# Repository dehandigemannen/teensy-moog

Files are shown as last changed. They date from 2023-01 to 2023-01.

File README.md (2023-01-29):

# Teensymoog board[untested]
> Simple board to provide inputs for the teensy audio library

## Components
A list of components can be found [here](https://docs.google.com/spreadsheets/d/1O3fiJveS2LG4Vu1J4wDSkKv0wMXK735ehudC7_bgVOY/edit?usp=sharing)

> This board uses the teensy 3.6 board with build-in dac, the next version of the board should work with the teensy 4.1 because of the shortage of the 3.6 teensy.

## Preview
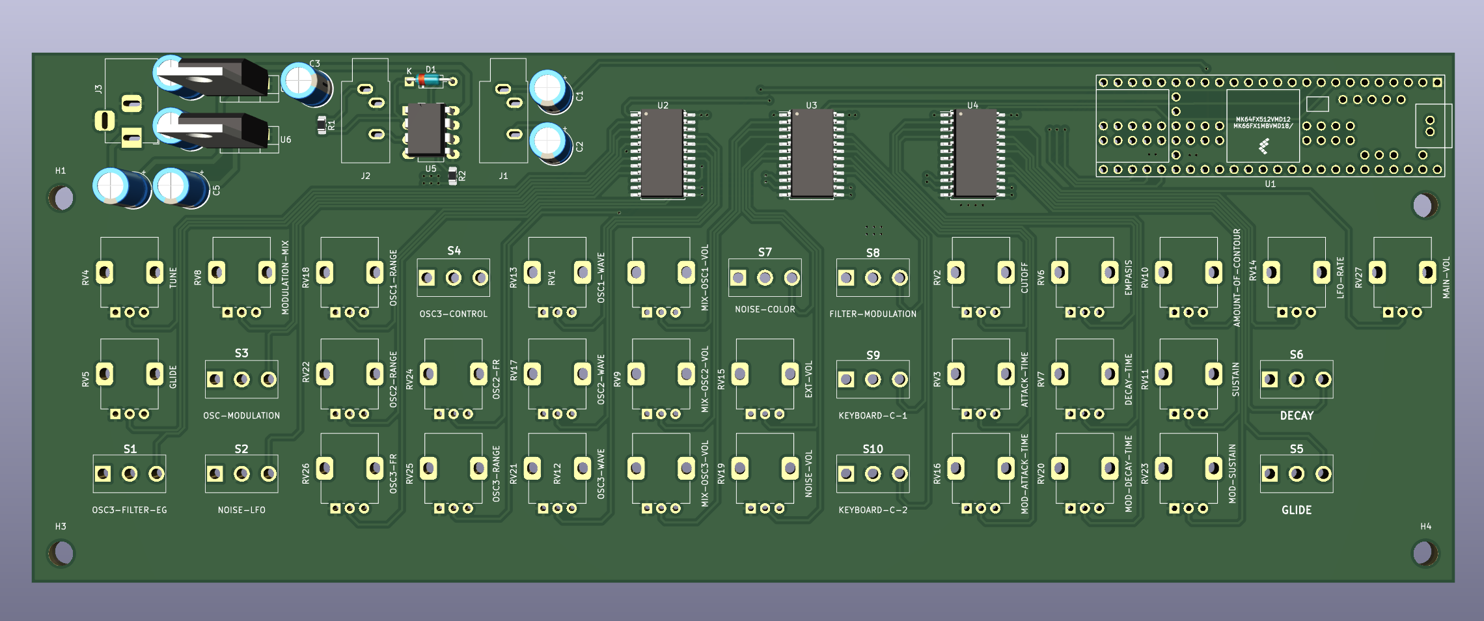
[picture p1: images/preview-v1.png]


## Rev2

- [] Connect switches to 3.3 V instead of ground.
- [] Create multiple boards to compensate for hight difference of pots and switches
- [] Use toggle switches that are on / of

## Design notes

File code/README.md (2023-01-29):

# Teensymoog - code

## Pins

```
TUNE = MUX_1_7
GLIDE = MUX_1_6
FILTER_EG = MUX_1_5 // SWITCH

MOD_MIX = MUX_1_4
MODULATION = MUX_1_2 // SWITCH
NOISE_LFO = MUX_1_1  // SWITCH

OSC_1_RANG = MUX_1_0
OSC_2_RANG = MUX_1_8
OSC_3_FR = MUX_1_14

OSC_3_CONTROL = MUX_1_3 // SWITCH
OSC_2_FR = MUX_1_13
OSC_3_RANGE = MUX_1_9

OSC_1_WAVE = MUX_1_12
OSC_2_WAVE = MUX_1_11
OSC_3_WAVE = MUX_1_10

OSC_1_VOL = MUX_2_7
OSC_2_VOL = MUX_2_6
OSC_3_VOL = MUX_2_5

NOISE_COLOR = MUX_2_4 // SWITCH
EXT_VOL = MUX_2_3
NOISE_VOL = MUX_2_2

FILTER_MOD = MUX_2_15   // SWITCH
KEYBOARD_C_1 = MUX_2_14 // SWITCH
KEYBOARD_C_2 = MUX_2_13 // SWITCH

CUTOFF = MUX_2_12
ATTACK_TIME = MUX_2_11
MOD_ATTACK_TIME = MUX_2_10

EMPHASIS = MUX_3_7
DECAY_TIME = MUX_3_6
MOD_DECAY_TIME = MUX_3_5

AMOUNT_OF_CONTOUR = MUX_3_15
SUSTAIN = MUX_3_14
MOD_SUSTAIN = MUX_3_13

LFO_RATE = MUX_3_10
DECAY = MUX_3_11 // SWITCH
GLIDE = MUX_3_12 // SWITCH

MAIN_VOL = MUX_3_9
```

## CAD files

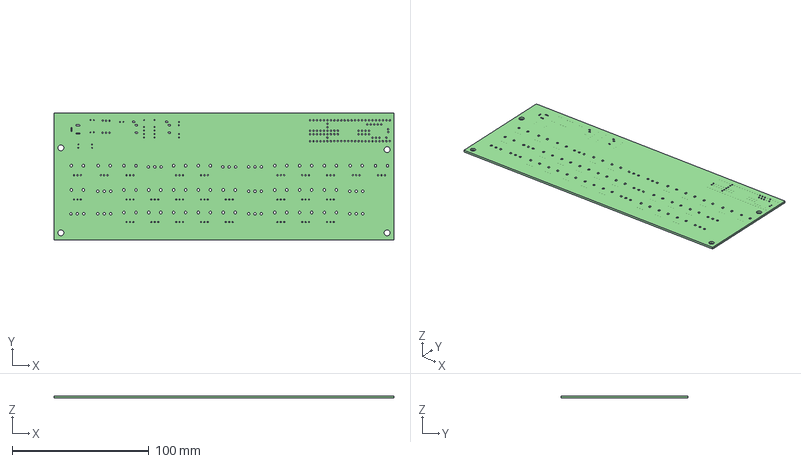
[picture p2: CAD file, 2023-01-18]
pcb/teensymoog.step
248.9 x 92.7 x 1.60 mm

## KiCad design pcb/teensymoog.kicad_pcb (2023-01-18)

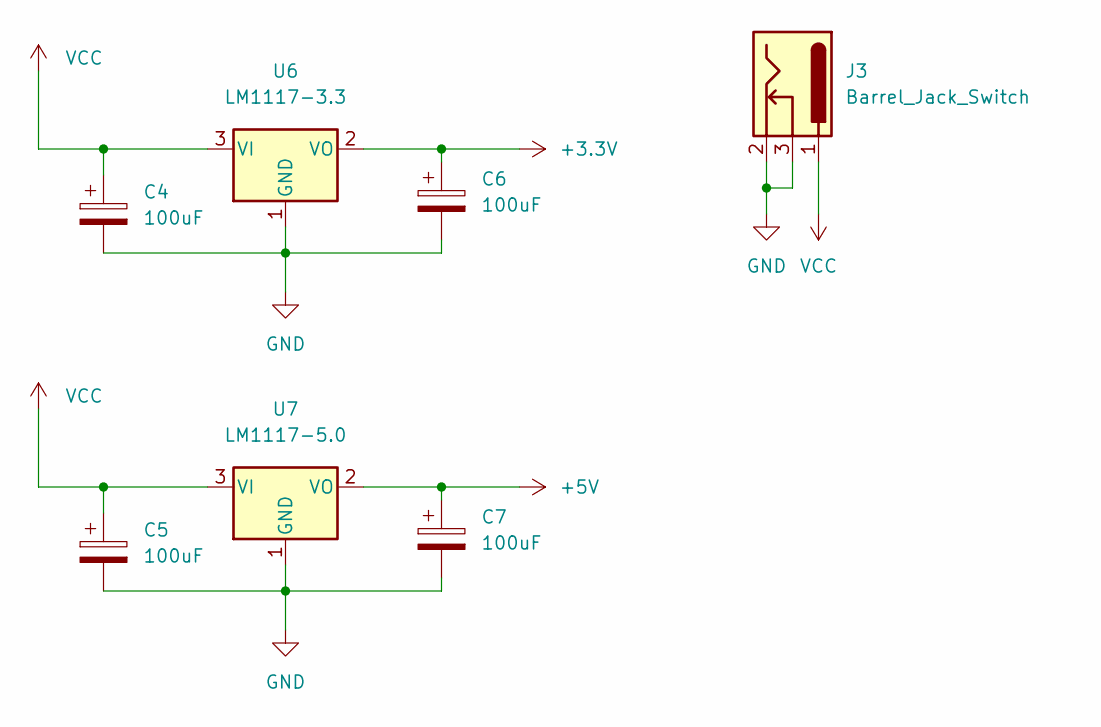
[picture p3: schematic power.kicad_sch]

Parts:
C4, C5, C6, C7: 100uF; CP_Radial_D6.3mm_P2.50mm
J3: Barrel_Jack_Switch; BarrelJack_Horizontal
U6: LM1117-3.3; TO-220-3_Vertical
U7: LM1117-5.0; TO-220-3_Vertical

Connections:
+3V3: C6.1, U6.2 (VO); also elsewhere on the board
+5V: C7.1, U7.2 (VO); also elsewhere on the board
GND: C4.2, C5.2, C6.2, C7.2, J3.2, J3.3, U6.1 (GND), U7.1 (GND); also elsewhere on the board
VCC: C4.1, C5.1, J3.1, U6.3 (VI), U7.3 (VI)

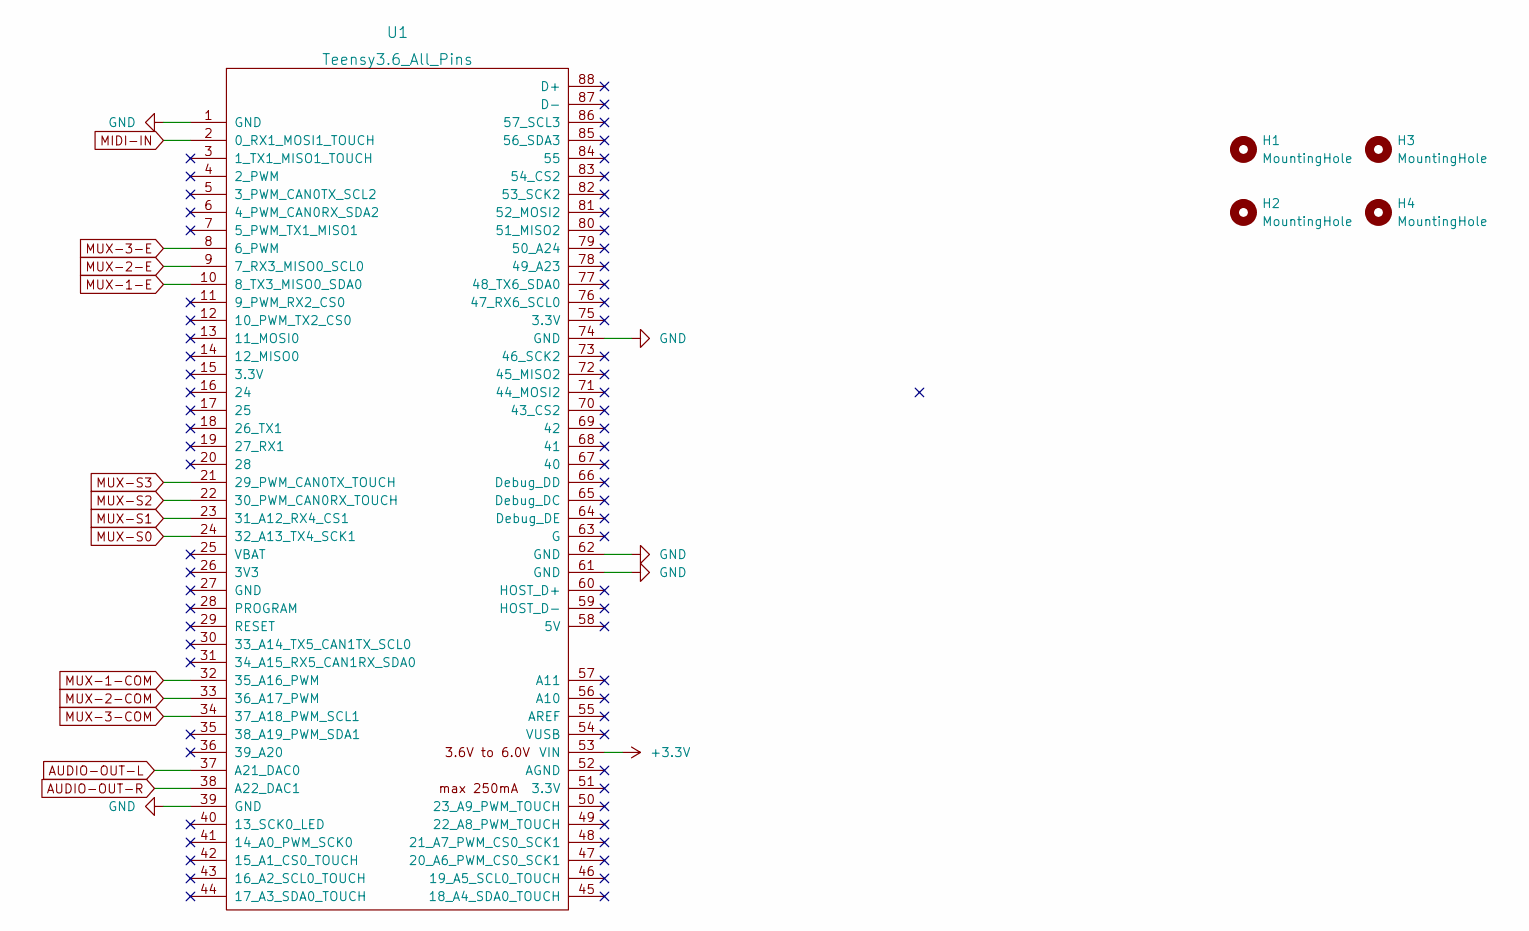
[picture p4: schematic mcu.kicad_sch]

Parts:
H1, H2, H3, H4: MountingHole; MountingHole_4.3mm_M4_DIN965
U1: Teensy3.6_All_Pins; Teensy35_36_All_Pins

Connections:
+3V3: U1.53 (VIN); also elsewhere on the board
AUDIO-OUT-L: U1.37 (A21_DAC0); also elsewhere on the board
AUDIO-OUT-R: U1.38 (A22_DAC1); also elsewhere on the board
GND: U1.1 (GND), U1.39 (GND), U1.61 (GND), U1.62 (GND), U1.74 (GND); also elsewhere on the board
MIDI-IN: U1.2 (0_RX1_MOSI1_TOUCH); also elsewhere on the board
MUX-1-COM: U1.32 (35_A16_PWM); also elsewhere on the board
MUX-1-E: U1.10 (8_TX3_MISO0_SDA0); also elsewhere on the board
MUX-2-COM: U1.33 (36_A17_PWM); also elsewhere on the board
MUX-2-E: U1.9 (7_RX3_MISO0_SCL0); also elsewhere on the board
MUX-3-COM: U1.34 (37_A18_PWM_SCL1); also elsewhere on the board
MUX-3-E: U1.8 (6_PWM); also elsewhere on the board
MUX-S0: U1.24 (32_A13_TX4_SCK1); also elsewhere on the board
MUX-S1: U1.23 (31_A12_RX4_CS1); also elsewhere on the board
MUX-S2: U1.22 (30_PWM_CAN0RX_TOUCH); also elsewhere on the board
MUX-S3: U1.21 (29_PWM_CAN0TX_TOUCH); also elsewhere on the board

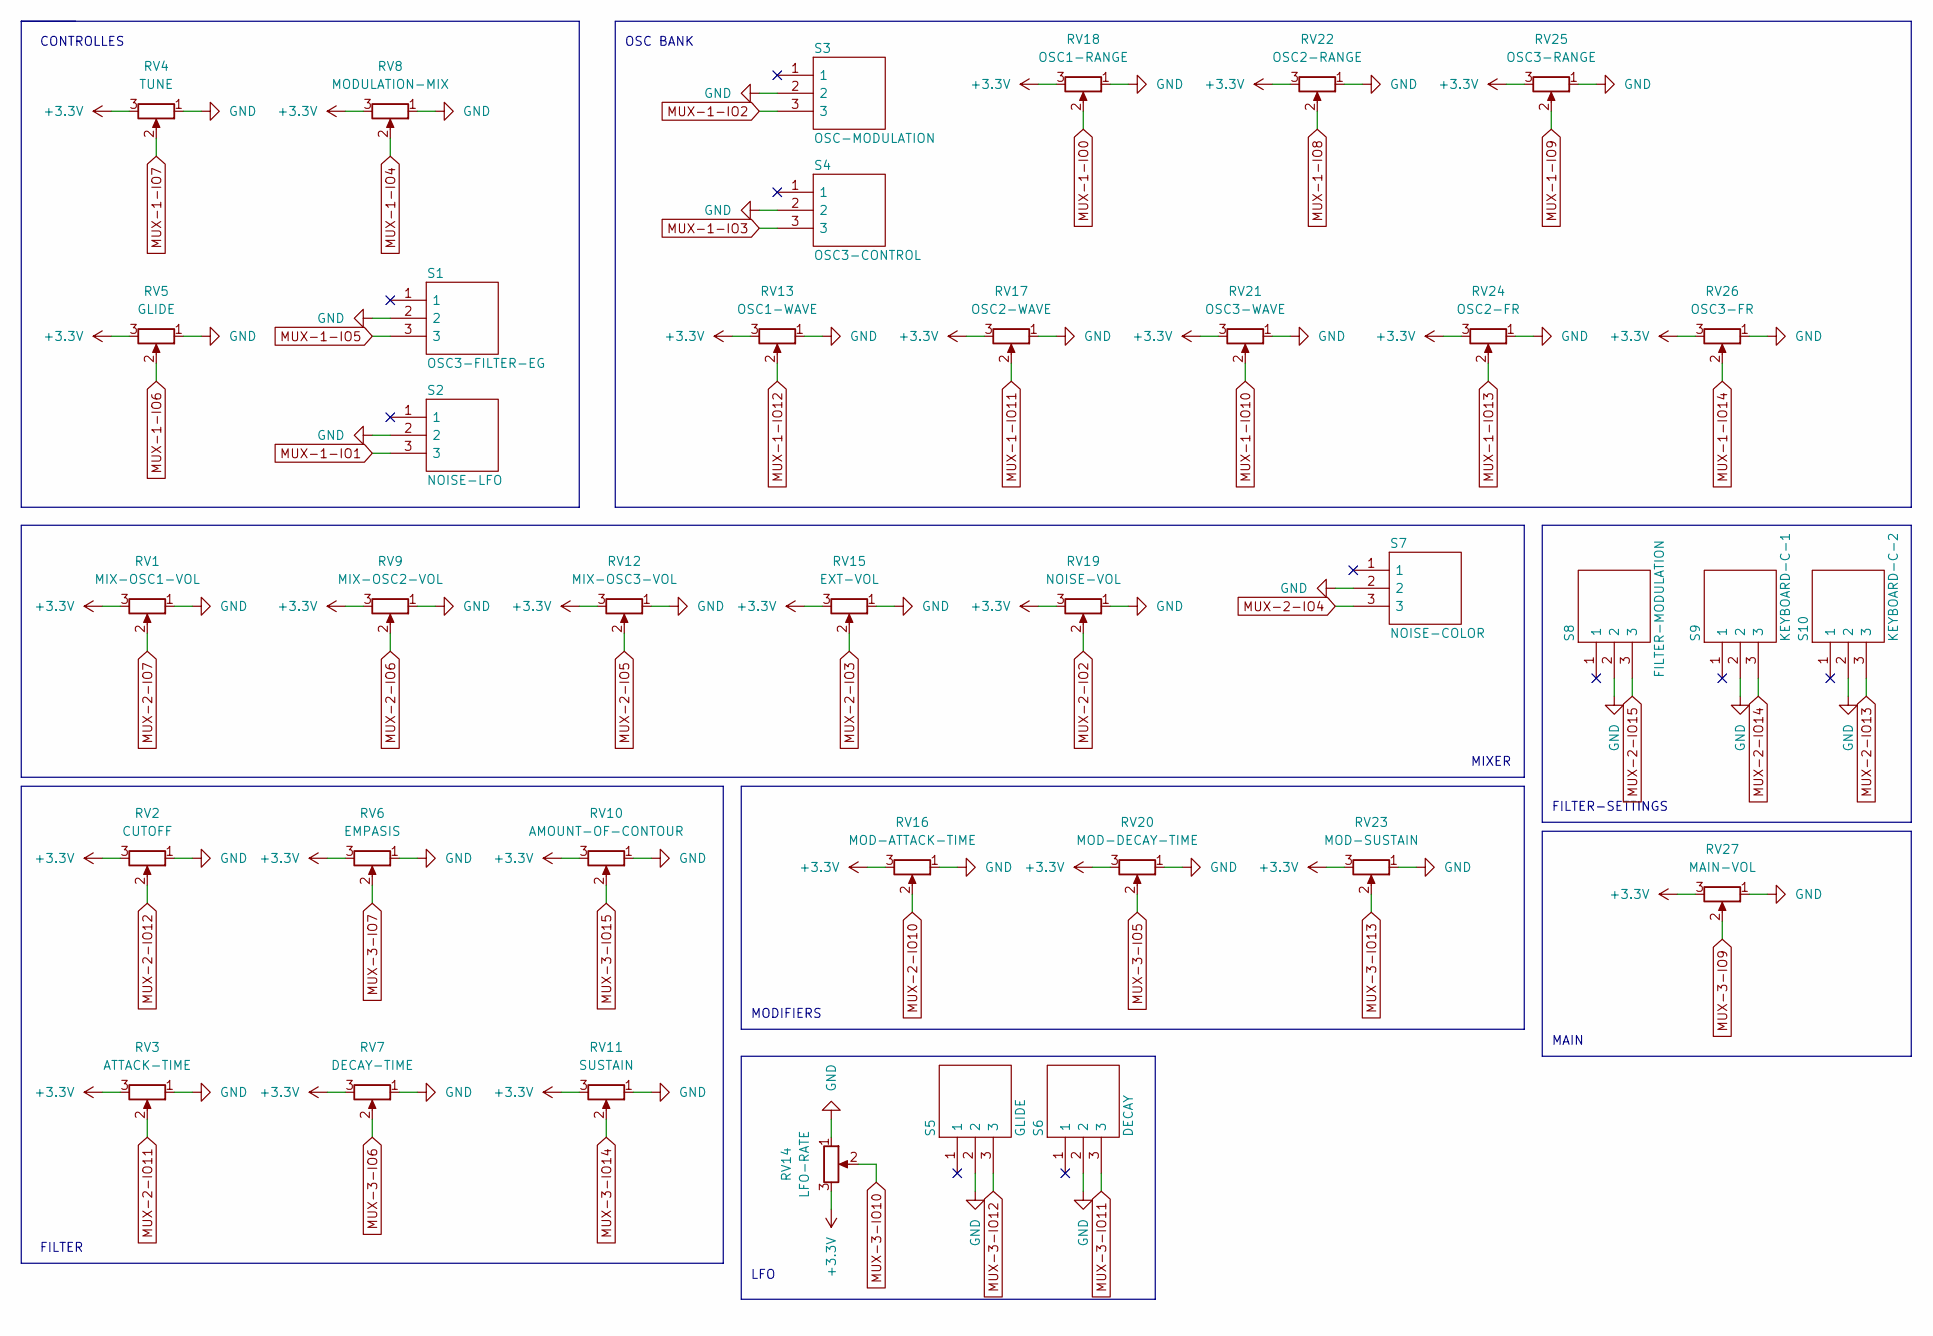
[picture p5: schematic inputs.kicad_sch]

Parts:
RV1: MIX-OSC1-VOL; Potentiometer_Alps_RK09K_Single_Vertical
RV2: CUTOFF; Potentiometer_Alps_RK09K_Single_Vertical
RV3: ATTACK-TIME; Potentiometer_Alps_RK09K_Single_Vertical
RV4: TUNE; Potentiometer_Alps_RK09K_Single_Vertical
RV5: GLIDE; Potentiometer_Alps_RK09K_Single_Vertical
RV6: EMPASIS; Potentiometer_Alps_RK09K_Single_Vertical
RV7: DECAY-TIME; Potentiometer_Alps_RK09K_Single_Vertical
RV8: MODULATION-MIX; Potentiometer_Alps_RK09K_Single_Vertical
RV9: MIX-OSC2-VOL; Potentiometer_Alps_RK09K_Single_Vertical
RV10: AMOUNT-OF-CONTOUR; Potentiometer_Alps_RK09K_Single_Vertical
RV11: SUSTAIN; Potentiometer_Alps_RK09K_Single_Vertical
RV12: MIX-OSC3-VOL; Potentiometer_Alps_RK09K_Single_Vertical
RV13: OSC1-WAVE; Potentiometer_Alps_RK09K_Single_Vertical
RV14: LFO-RATE; Potentiometer_Alps_RK09K_Single_Vertical
RV15: EXT-VOL; Potentiometer_Alps_RK09K_Single_Vertical
RV16: MOD-ATTACK-TIME; Potentiometer_Alps_RK09K_Single_Vertical
RV17: OSC2-WAVE; Potentiometer_Alps_RK09K_Single_Vertical
RV18: OSC1-RANGE; Potentiometer_Alps_RK09K_Single_Vertical
RV19: NOISE-VOL; Potentiometer_Alps_RK09K_Single_Vertical
RV20: MOD-DECAY-TIME; Potentiometer_Alps_RK09K_Single_Vertical
RV21: OSC3-WAVE; Potentiometer_Alps_RK09K_Single_Vertical
RV22: OSC2-RANGE; Potentiometer_Alps_RK09K_Single_Vertical
RV23: MOD-SUSTAIN; Potentiometer_Alps_RK09K_Single_Vertical
RV24: OSC2-FR; Potentiometer_Alps_RK09K_Single_Vertical
RV25: OSC3-RANGE; Potentiometer_Alps_RK09K_Single_Vertical
RV26: OSC3-FR; Potentiometer_Alps_RK09K_Single_Vertical
RV27: MAIN-VOL; Potentiometer_Alps_RK09K_Single_Vertical
S1: OSC3-FILTER-EG; 2M1SP3T1B1M2QE; Manufacturer_Part_Number 2M1-SP1-T1-B1-M2QE; Mouser Part Number 691-2M1-SP1-T1B1M2QE
S2: NOISE-LFO; 2M1SP3T1B1M2QE; Manufacturer_Part_Number 2M1-SP1-T1-B1-M2QE; Mouser Part Number 691-2M1-SP1-T1B1M2QE
S3: OSC-MODULATION; 2M1SP3T1B1M2QE; Manufacturer_Part_Number 2M1-SP1-T1-B1-M2QE; Mouser Part Number 691-2M1-SP1-T1B1M2QE
S4: OSC3-CONTROL; 2M1SP3T1B1M2QE; Manufacturer_Part_Number 2M1-SP1-T1-B1-M2QE; Mouser Part Number 691-2M1-SP1-T1B1M2QE
S5: GLIDE; 2M1SP3T1B1M2QE; Manufacturer_Part_Number 2M1-SP1-T1-B1-M2QE; Mouser Part Number 691-2M1-SP1-T1B1M2QE
S6: DECAY; 2M1SP3T1B1M2QE; Manufacturer_Part_Number 2M1-SP1-T1-B1-M2QE; Mouser Part Number 691-2M1-SP1-T1B1M2QE
S7: NOISE-COLOR; 2M1SP3T1B1M2QE; Manufacturer_Part_Number 2M1-SP1-T1-B1-M2QE; Mouser Part Number 691-2M1-SP1-T1B1M2QE
S8: FILTER-MODULATION; 2M1SP3T1B1M2QE; Manufacturer_Part_Number 2M1-SP1-T1-B1-M2QE; Mouser Part Number 691-2M1-SP1-T1B1M2QE
S9: KEYBOARD-C-1; 2M1SP3T1B1M2QE; Manufacturer_Part_Number 2M1-SP1-T1-B1-M2QE; Mouser Part Number 691-2M1-SP1-T1B1M2QE
S10: KEYBOARD-C-2; 2M1SP3T1B1M2QE; Manufacturer_Part_Number 2M1-SP1-T1-B1-M2QE; Mouser Part Number 691-2M1-SP1-T1B1M2QE

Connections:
+3V3: RV1.3, RV2.3, RV3.3, RV4.3, RV5.3, RV6.3, RV7.3, RV8.3, RV9.3, RV10.3, RV11.3, RV12.3, RV13.3, RV14.3, RV15.3, RV16.3, RV17.3, RV18.3, RV19.3, RV20.3, RV21.3, RV22.3, RV23.3, RV24.3, RV25.3, RV26.3, RV27.3; also elsewhere on the board
GND: RV1.1, RV2.1, RV3.1, RV4.1, RV5.1, RV6.1, RV7.1, RV8.1, RV9.1, RV10.1, RV11.1, RV12.1, RV13.1, RV14.1, RV15.1, RV16.1, RV17.1, RV18.1, RV19.1, RV20.1, RV21.1, RV22.1, RV23.1, RV24.1, RV25.1, RV26.1, RV27.1, S1.2, S2.2, S3.2, S4.2, S5.2, S6.2, S7.2, S8.2, S9.2, S10.2; also elsewhere on the board
MUX-1-IO0: RV18.2; also elsewhere on the board
MUX-1-IO1: S2.3; also elsewhere on the board
MUX-1-IO2: S3.3; also elsewhere on the board
MUX-1-IO3: S4.3; also elsewhere on the board
MUX-1-IO4: RV8.2; also elsewhere on the board
MUX-1-IO5: S1.3; also elsewhere on the board
MUX-1-IO6: RV5.2; also elsewhere on the board
MUX-1-IO7: RV4.2; also elsewhere on the board
MUX-1-IO8: RV22.2; also elsewhere on the board
MUX-1-IO9: RV25.2; also elsewhere on the board
MUX-1-IO10: RV21.2; also elsewhere on the board
MUX-1-IO11: RV17.2; also elsewhere on the board
MUX-1-IO12: RV13.2; also elsewhere on the board
MUX-1-IO13: RV24.2; also elsewhere on the board
MUX-1-IO14: RV26.2; also elsewhere on the board
MUX-2-IO2: RV19.2; also elsewhere on the board
MUX-2-IO3: RV15.2; also elsewhere on the board
MUX-2-IO4: S7.3; also elsewhere on the board
MUX-2-IO5: RV12.2; also elsewhere on the board
MUX-2-IO6: RV9.2; also elsewhere on the board
MUX-2-IO7: RV1.2; also elsewhere on the board
MUX-2-IO10: RV16.2; also elsewhere on the board
MUX-2-IO11: RV3.2; also elsewhere on the board
MUX-2-IO12: RV2.2; also elsewhere on the board
MUX-2-IO13: S10.3; also elsewhere on the board
MUX-2-IO14: S9.3; also elsewhere on the board
MUX-2-IO15: S8.3; also elsewhere on the board
MUX-3-IO5: RV20.2; also elsewhere on the board
MUX-3-IO6: RV7.2; also elsewhere on the board
MUX-3-IO7: RV6.2; also elsewhere on the board
MUX-3-IO9: RV27.2; also elsewhere on the board
MUX-3-IO10: RV14.2; also elsewhere on the board
MUX-3-IO11: S6.3; also elsewhere on the board
MUX-3-IO12: S5.3; also elsewhere on the board
MUX-3-IO13: RV23.2; also elsewhere on the board
MUX-3-IO14: RV11.2; also elsewhere on the board
MUX-3-IO15: RV10.2; also elsewhere on the board

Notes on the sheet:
MIXER
MODIFIERS
FILTER-SETTINGS
LFO
OSC BANK
CONTROLLES
MAIN
FILTER

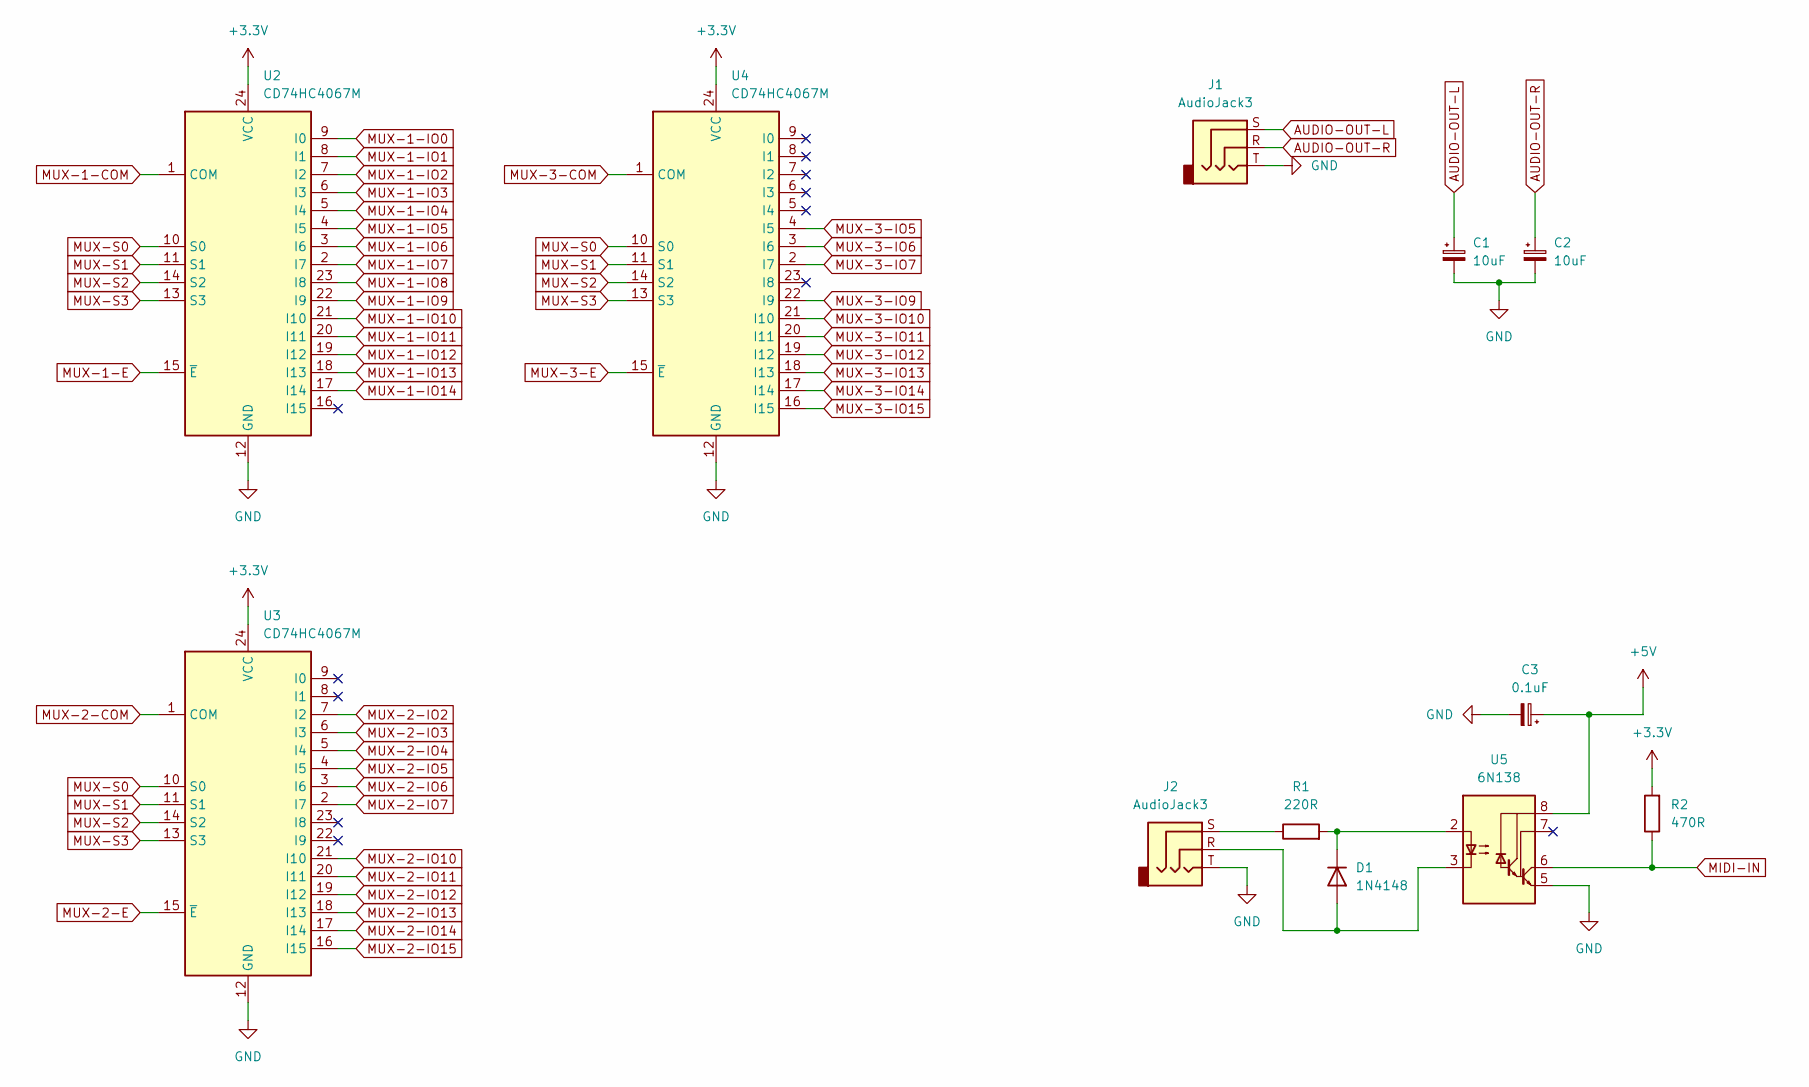
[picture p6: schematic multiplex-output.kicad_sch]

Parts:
C1, C2: 10uF; CP_Radial_D6.3mm_P2.50mm
C3: 0.1uF; CP_Radial_D6.3mm_P2.50mm
D1: 1N4148; D_DO-35_SOD27_P7.62mm_Horizontal
J1, J2: AudioJack3; Jack_3.5mm_CUI_SJ1-3533NG_Horizontal
R1: 220R; R_0805_2012Metric_Pad1.20x1.40mm_HandSolder
R2: 470R; R_0805_2012Metric_Pad1.20x1.40mm_HandSolder
U2, U3, U4: CD74HC4067M; SOIC-24W_7.5x15.4mm_P1.27mm
U5: 6N138; DIP-8_W7.62mm_LongPads

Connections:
+3V3: R2.2, U2.24 (VCC), U3.24 (VCC), U4.24 (VCC); also elsewhere on the board
+5V: C3.1, U5.8 (VCC); also elsewhere on the board
AUDIO-OUT-L: C1.1, J1.S; also elsewhere on the board
AUDIO-OUT-R: C2.1, J1.R; also elsewhere on the board
GND: C1.2, C2.2, C3.2, J1.T, J2.T, U2.12 (GND), U3.12 (GND), U4.12 (GND), U5.5 (GND); also elsewhere on the board
MIDI-IN: R2.1, U5.6 (VO2); also elsewhere on the board
MUX-1-COM: U2.1 (COM); also elsewhere on the board
MUX-1-E: U2.15 (~E); also elsewhere on the board
MUX-1-IO0: U2.9 (I0); also elsewhere on the board
MUX-1-IO1: U2.8 (I1); also elsewhere on the board
MUX-1-IO2: U2.7 (I2); also elsewhere on the board
MUX-1-IO3: U2.6 (I3); also elsewhere on the board
MUX-1-IO4: U2.5 (I4); also elsewhere on the board
MUX-1-IO5: U2.4 (I5); also elsewhere on the board
MUX-1-IO6: U2.3 (I6); also elsewhere on the board
MUX-1-IO7: U2.2 (I7); also elsewhere on the board
MUX-1-IO8: U2.23 (I8); also elsewhere on the board
MUX-1-IO9: U2.22 (I9); also elsewhere on the board
MUX-1-IO10: U2.21 (I10); also elsewhere on the board
MUX-1-IO11: U2.20 (I11); also elsewhere on the board
MUX-1-IO12: U2.19 (I12); also elsewhere on the board
MUX-1-IO13: U2.18 (I13); also elsewhere on the board
MUX-1-IO14: U2.17 (I14); also elsewhere on the board
MUX-2-COM: U3.1 (COM); also elsewhere on the board
MUX-2-E: U3.15 (~E); also elsewhere on the board
MUX-2-IO2: U3.7 (I2); also elsewhere on the board
MUX-2-IO3: U3.6 (I3); also elsewhere on the board
MUX-2-IO4: U3.5 (I4); also elsewhere on the board
MUX-2-IO5: U3.4 (I5); also elsewhere on the board
MUX-2-IO6: U3.3 (I6); also elsewhere on the board
MUX-2-IO7: U3.2 (I7); also elsewhere on the board
MUX-2-IO10: U3.21 (I10); also elsewhere on the board
MUX-2-IO11: U3.20 (I11); also elsewhere on the board
MUX-2-IO12: U3.19 (I12); also elsewhere on the board
MUX-2-IO13: U3.18 (I13); also elsewhere on the board
MUX-2-IO14: U3.17 (I14); also elsewhere on the board
MUX-2-IO15: U3.16 (I15); also elsewhere on the board
MUX-3-COM: U4.1 (COM); also elsewhere on the board
MUX-3-E: U4.15 (~E); also elsewhere on the board
MUX-3-IO5: U4.4 (I5); also elsewhere on the board
MUX-3-IO6: U4.3 (I6); also elsewhere on the board
MUX-3-IO7: U4.2 (I7); also elsewhere on the board
MUX-3-IO9: U4.22 (I9); also elsewhere on the board
MUX-3-IO10: U4.21 (I10); also elsewhere on the board
MUX-3-IO11: U4.20 (I11); also elsewhere on the board
MUX-3-IO12: U4.19 (I12); also elsewhere on the board
MUX-3-IO13: U4.18 (I13); also elsewhere on the board
MUX-3-IO14: U4.17 (I14); also elsewhere on the board
MUX-3-IO15: U4.16 (I15); also elsewhere on the board
MUX-S0: U2.10 (S0), U3.10 (S0), U4.10 (S0); also elsewhere on the board
MUX-S1: U2.11 (S1), U3.11 (S1), U4.11 (S1); also elsewhere on the board
MUX-S2: U2.14 (S2), U3.14 (S2), U4.14 (S2); also elsewhere on the board
MUX-S3: U2.13 (S3), U3.13 (S3), U4.13 (S3); also elsewhere on the board
unnamed: D1.1 (K), R1.2, U5.2 (C1)
unnamed: D1.2 (A), J2.R, U5.3 (C2)
unnamed: J2.S, R1.1

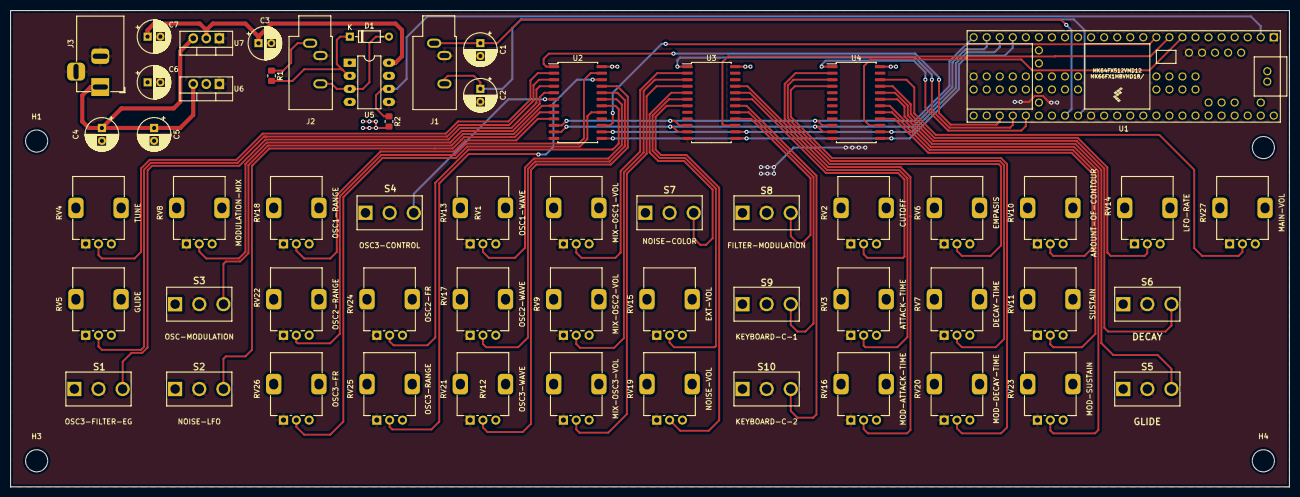
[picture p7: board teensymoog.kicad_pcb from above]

Board: 2 copper layers, 248.9 x 92.7 mm, 61 parts (0 on the bottom side), 57 nets.

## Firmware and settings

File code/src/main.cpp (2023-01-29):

#include <Arduino.h>
#include <HC4067.h>
#include <Helpers.h>

#define MUX_1_COM 35
#define MUX_1_ENABLE 8

#define MUX_2_COM 36
#define MUX_2_ENABLE 7

#define MUX_3_COM 37
#define MUX_3_ENABLE 6

#define MUX_S0 32
#define MUX_S1 31
#define MUX_S2 30
#define MUX_S3 29

HC4067 mux1;
HC4067 mux2;
HC4067 mux3;

int tune = 0;
int glide = 0;
int filter_eg = 0; // switch

int mod_mix = 0;
int modulation = 0; // switch
int noise_lfo = 0;  // switch

int osc_1_rang = 0;
int osc_2_rang = 0;
int osc_3_fr = 0;

int osc_3_control = 0; // switch
int osc_2_fr = 0;
int osc_3_range = 0;

int osc_1_wave = 0;
int osc_2_wave = 0;
int osc_3_wave = 0;

int osc_1_vol = 0;
int osc_2_vol = 0;
int osc_3_vol = 0;

int noise_color = 0; // switch
int ext_vol = 0;
int noise_vol = 0;

int filter_mod = 0;   // switch
int keyboard_c_1 = 0; // switch
int keyboard_c_2 = 0; // switch

int cutoff = 0;
int attack_time = 0;
int mod_attack_time = 0;

int emphasis = 0;
int decay_time = 0;
int mod_decay_time = 0;

int amount_of_contour = 0;
int sustain = 0;
int mod_sustain = 0;

int lfo_rate = 0;
int decay = 0;        // switch
int glide_switch = 0; // switch

int main_vol = 0;

void logInput(String label, int value)
{
  Serial.print(label);
  Serial.print(": ");
  Serial.println(value);
}

void updateMux1Values()
{
  mux1.enable();

  tune = mux1.read(HC4067_CHANNEL_7);
  glide = mux1.read(HC4067_CHANNEL_6);
  filter_eg = mux1.read(HC4067_CHANNEL_5); // switch

  mod_mix = mux1.read(HC4067_CHANNEL_4);
  modulation = mux1.read(HC4067_CHANNEL_2); // switch
  noise_lfo = mux1.read(HC4067_CHANNEL_1);  // switch

  osc_1_rang = mux1.read(HC4067_CHANNEL_0);
  osc_2_rang = mux1.read(HC4067_CHANNEL_8);
  osc_3_fr = mux1.read(HC4067_CHANNEL_14);

  osc_3_control = mux1.read(HC4067_CHANNEL_3); // switch
  osc_2_fr = mux1.read(HC4067_CHANNEL_13);
  osc_3_range = mux1.read(HC4067_CHANNEL_9);

  osc_1_wave = mux1.read(HC4067_CHANNEL_12);
  osc_2_wave = mux1.read(HC4067_CHANNEL_11);
  osc_3_wave = mux1.read(HC4067_CHANNEL_10);

  mux1.disable();
}

void updateMux2Values()
{
  mux2.enable();

  osc_1_vol = mux2.read(HC4067_CHANNEL_7);
  osc_2_vol = mux2.read(HC4067_CHANNEL_6);
  osc_3_vol = mux2.read(HC4067_CHANNEL_5);

  noise_color = mux2.read(HC4067_CHANNEL_4); // switch
  ext_vol = mux2.read(HC4067_CHANNEL_3);
  noise_vol = mux2.read(HC4067_CHANNEL_2);

  filter_mod = mux2.read(HC4067_CHANNEL_15);   // switch
  keyboard_c_1 = mux2.read(HC4067_CHANNEL_14); // switch
  keyboard_c_2 = mux2.read(HC4067_CHANNEL_13); // switch

  cutoff = mux2.read(HC4067_CHANNEL_12);
  attack_time = mux2.read(HC4067_CHANNEL_11);
  mod_attack_time = mux2.read(HC4067_CHANNEL_10);

  mux2.disable();
}

void updateMux3Values()
{
  mux3.enable();

  emphasis = mux3.read(HC4067_CHANNEL_7);
  decay_time = mux3.read(HC4067_CHANNEL_6);
  mod_decay_time = mux3.read(HC4067_CHANNEL_5);

  amount_of_contour = mux3.read(HC4067_CHANNEL_15);
  sustain = mux3.read(HC4067_CHANNEL_14);
  mod_sustain = mux3.read(HC4067_CHANNEL_13);

  lfo_rate = mux3.read(HC4067_CHANNEL_10);
  decay = mux3.read(HC4067_CHANNEL_11);        // switch
  glide_switch = mux3.read(HC4067_CHANNEL_12); // switch

  main_vol = mux3.read(HC4067_CHANNEL_9);

  mux3.disable();
}

void logInputInfo()
{
  logInput("tune", tune);
  logInput("glide", glide);
  logInput("filter_eg", filter_eg);

  logInput("mod_mix", mod_mix);
  logInput("modulation", modulation);
  logInput("noise_lfo", noise_lfo);

  logInput("osc_1_rang", osc_1_rang);
  logInput("osc_2_rang", osc_2_rang);
  logInput("osc_3_fr", osc_3_fr);

  logInput("osc_3_control", osc_3_control);
  logInput("osc_2_fr", osc_2_fr);
  logInput("osc_3_range", osc_3_range);

  logInput("osc_1_wave", osc_1_wave);
  logInput("osc_2_wave", osc_2_wave);
  logInput("osc_3_wave", osc_3_wave);

  logInput("osc_1_vol", osc_1_vol);
  logInput("osc_2_vol", osc_2_vol);
  logInput("osc_3_vol", osc_3_vol);

  logInput("noise_color", noise_color);
  logInput("ext_vol", ext_vol);
  logInput("noise_vol", noise_vol);

  logInput("filter_mod", filter_mod);
  logInput("keyboard_c_1", keyboard_c_1);
  logInput("keyboard_c_2", keyboard_c_2);

  logInput("cutoff", cutoff);
  logInput("attack_time", attack_time);
  logInput("mod_attack_time", mod_attack_time);

  logInput("emphasis", emphasis); // BROKEN?
  logInput("decay_time", decay_time);
  logInput("mod_decay_time", mod_decay_time);

  logInput("amount_of_contour", amount_of_contour);
  logInput("sustain", sustain);
  logInput("mod_sustain", mod_sustain);

  logInput("lfo_rate", lfo_rate);
  logInput("decay", decay);
  logInput("glide_switch", glide_switch);

  logInput("main_vol", main_vol);
}

void setup()
{
  Serial.begin(115200);

  mux1.begin(MUX_1_ENABLE, MUX_1_COM, MUX_S0, MUX_S1, MUX_S2, MUX_S3);
  mux2.begin(MUX_2_ENABLE, MUX_2_COM, MUX_S0, MUX_S1, MUX_S2, MUX_S3);
  mux3.begin(MUX_3_ENABLE, MUX_3_COM, MUX_S0, MUX_S1, MUX_S2, MUX_S3);

  pinMode(LED_BUILTIN, OUTPUT);
}

void loop()
{
  digitalWrite(LED_BUILTIN, HIGH);

  updateMux1Values();
  updateMux2Values();
  updateMux3Values();

  Serial.println("---------");

  digitalWrite(LED_BUILTIN, LOW);
  delay(100);
}

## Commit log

2023-01-18 Add first version of the pcb
    [inputs.kicad_sch, mcu.kicad_sch, multiplex-output.kicad_sch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]
2023-01-22 Move files to pcb folder
    [inputs.kicad_sch, mcu.kicad_sch, multiplex-output.kicad_sch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]
2023-01-27 Fix bug with select pins and inverted enable pin
